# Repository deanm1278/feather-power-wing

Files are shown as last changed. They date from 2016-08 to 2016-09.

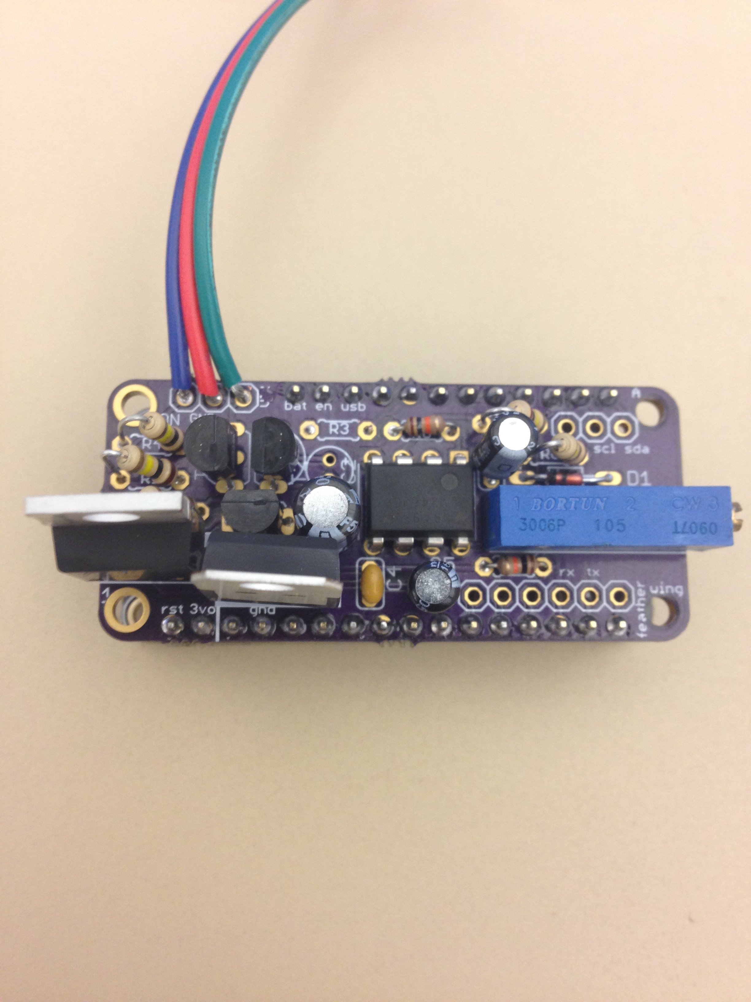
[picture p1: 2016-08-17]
IMG_4063.JPG

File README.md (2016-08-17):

# feather-power-wing
a wing to turn on and off a feather board with a signal voltage

This is useful for battery powered applications where you don't wanna waste your mAh on sleep mode or voltage regulators or what have you.

The battery is connected to the VIN and GND pins, and if a voltage applied to the VON pin for a period of time set by R7 (up to 1.5 sec with given values of C1 and R7) then the feather will turn on.

If pin 12 on the feather goes high, the feather will turn itself off. The onboard regulator works with supply voltages up to 15V.

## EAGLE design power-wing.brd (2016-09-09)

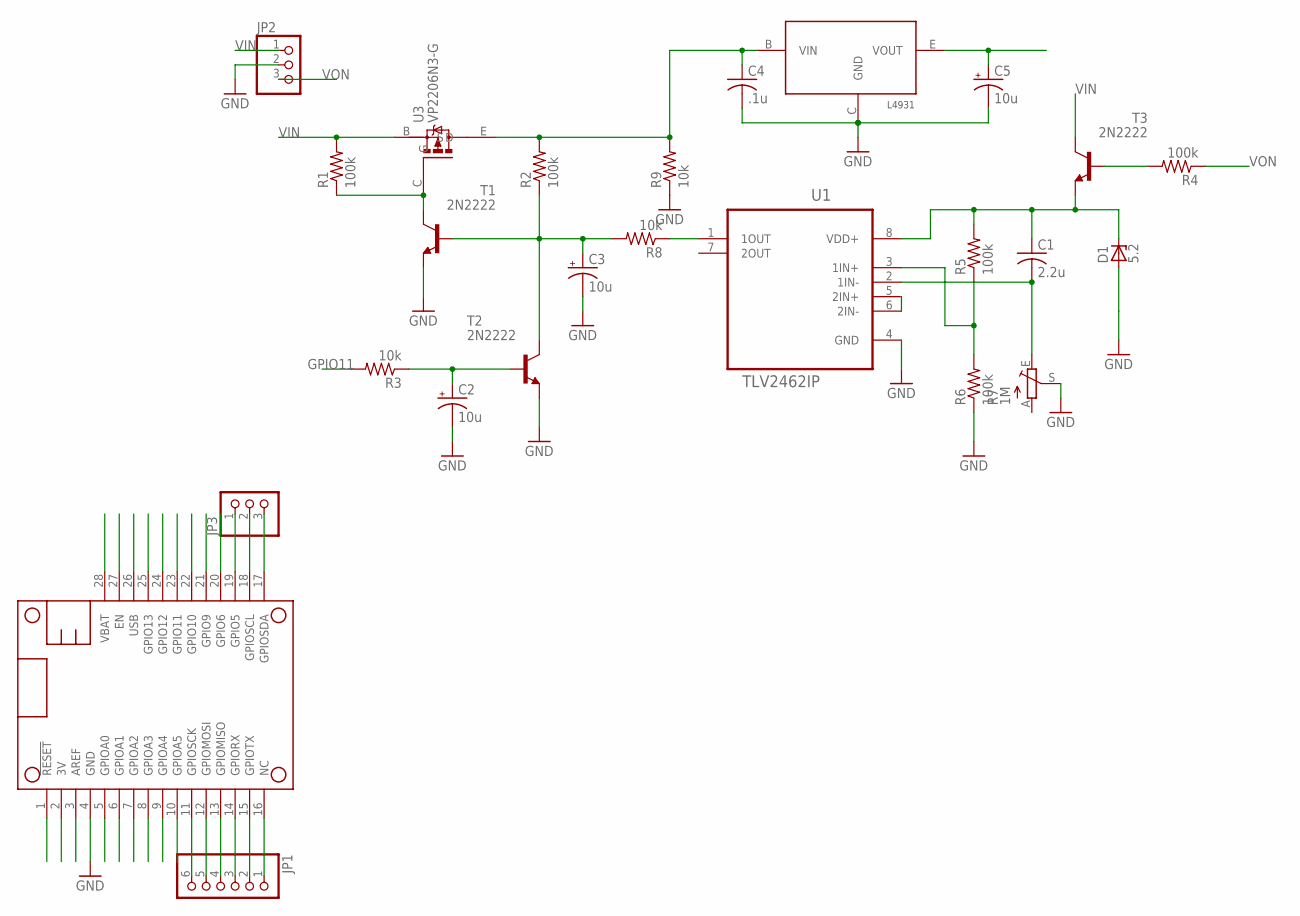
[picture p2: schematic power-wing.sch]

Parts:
C1: 2.2u; C025-024X044
C2, C3, C5: 10u; E1,8-4
C4: .1u; C025-024X044
D1: 5.2; DO34Z7
JP1: PINHD-1X6; 1X06
JP2, JP3: PINHD-1X3; 1X03
MS1: FEATHERWING
R1, R2, R4, R5, R6: 100k; 0204/5
R3, R8, R9: 10k; 0204/5
R7: 1M; PT-SPIN
T1, T2, T3: 2N2222; TO92-EBC-OVAL
U1: TLV2462IP; DIP254P762X508-8
U2: L4931; TO92-BCE
U3: VP2206N3-G; TO92-BCE

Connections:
3V: C5.+, MS1.2 (3V), U2.E (VOUT)
AREF: MS1.3 (AREF)
GND: C2.-, C3.-, C4.2, C5.-, JP2.2, MS1.4 (GND), R6.1, R7.S, R9.1, T1.E, T2.E, U1.4 (GND), U2.C (GND)
GPIO11: MS1.23 (GPIO11), R3.2
GPIO12: MS1.24 (GPIO12)
unnamed: JP1.1, MS1.16 (NC)
unnamed: JP1.2, MS1.15 (GPIOTX)
unnamed: JP1.3, MS1.14 (GPIORX)
unnamed: JP1.4, MS1.13 (GPIOMISO)
unnamed: JP1.5, MS1.12 (GPIOMOSI)
unnamed: JP1.6, MS1.11 (GPIOSCK)
unnamed: R1.1, T1.C, U3.C (G)
unnamed: C3.+, R2.1, R8.2, T1.B, T2.C
unnamed: JP3.1, MS1.19 (GPIO5)
unnamed: JP3.2, MS1.18 (GPIOSCL)
unnamed: JP3.3, MS1.17 (GPIOSDA)
unnamed: C2.+, R3.1, T2.B
unnamed: R5.1, R6.2, U1.3 (1IN+)
unnamed: C1.1, D1.C, R5.2, T3.E, U1.8 (VDD+)
unnamed: C1.2, R7.E, U1.2 (1IN-)
unnamed: R4.2, T3.B
unnamed: U1.5 (2IN+), U1.6 (2IN-)
unnamed: R8.1, U1.1 (1OUT)
USB: MS1.26 (USB)
VBAT: MS1.28 (VBAT)
VIN: JP2.1, R1.2, T3.C, U3.B (S)
VON: JP2.3, R4.1
VOUT: C4.1, R2.2, R9.2, U2.B (VIN), U3.E (D)

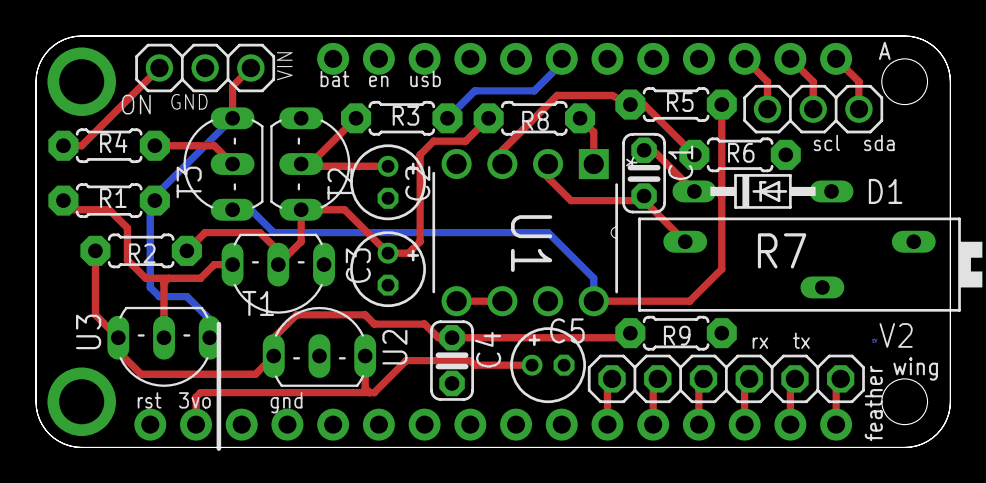
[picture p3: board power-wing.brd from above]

Board: 2 copper layers, 50.8 x 22.9 mm, 25 parts (0 on the bottom side), 24 nets.

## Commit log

2016-08-17 DM: added board image
2016-09-06 off switch to GPIO11 instead of 12 since that is used for sleep
    [power-wing.brd, power-wing.sch]
2016-09-07 lets use some smaller parts
    [power-wing.brd, power-wing.sch]
2016-09-09 fixed the names
    [power-wing.brd, power-wing.sch]
